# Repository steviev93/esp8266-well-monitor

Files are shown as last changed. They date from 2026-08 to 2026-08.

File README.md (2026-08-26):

ESP8266 Well Water Monitor

A solar-powered IoT system for remotely monitoring residential well-water depth using an ESP8266, ADS1115 ADC, and 4–20 mA submersible pressure sensor.

Overview

The monitor converts the sensor's 4–20 mA output into a measurable voltage using a 150 Ω shunt resistor, producing approximately 0.6–3.0 V across the sensor's operating range. An ADS1115 digitizes the signal and communicates with the ESP8266 over I²C.

The ESP8266 processes the reading, converts it into water-level data, and transmits telemetry over Wi-Fi. The sensor loop is switched by a MOSFET so it can be powered only when a measurement is required.

Hardware
ESP8266 NodeMCU
ADS1115 16-bit ADC
4–20 mA submersible pressure/depth sensor
150 Ω current-shunt resistor
IRLB8721 MOSFET for sensor power control
12 V LiFePO4 battery
Solar charging system
Custom KiCad PCB

KiCad schematic and PCB source files are available in hardware/.

Firmware

Firmware is written in C and organized into separate hardware, driver, service, and application layers.

Key features include:

ADS1115 I²C driver
4–20 mA signal conversion and water-level calculation
Wi-Fi connection management
HTTP telemetry
In-memory buffering during connection failures
NVS-backed storage for retained data/configuration
Automatic replay of buffered telemetry after reconnect
Health monitoring and recovery logic
PCB V1 Erratum

The first PCB revision contained an error in the ADS1115 power connection. The ADC supply was routed to the wrong ESP8266 board power connection rather than the regulated 3.3 V rail, resulting in unstable operation and ESP8266 resets.

The prototype was reworked by cutting the incorrect VCC trace and manually connecting the ADS1115 supply to 3.3 V.

A future PCB revision should correct the power-net assignment in the schematic/layout.

Repository Structure
application/ – sampling, telemetry, buffering, supervision
drivers/ – ADS1115 device driver
hal/ – GPIO and I²C hardware abstraction
services/ – Wi-Fi, HTTP, and persistent storage
hardware/ – KiCad schematic, PCB layout, and schematic image
main/ – application entry point
Status

Functional prototype and firmware complete. Hardware design is retained in the repository for continued PCB revision and field-development work.

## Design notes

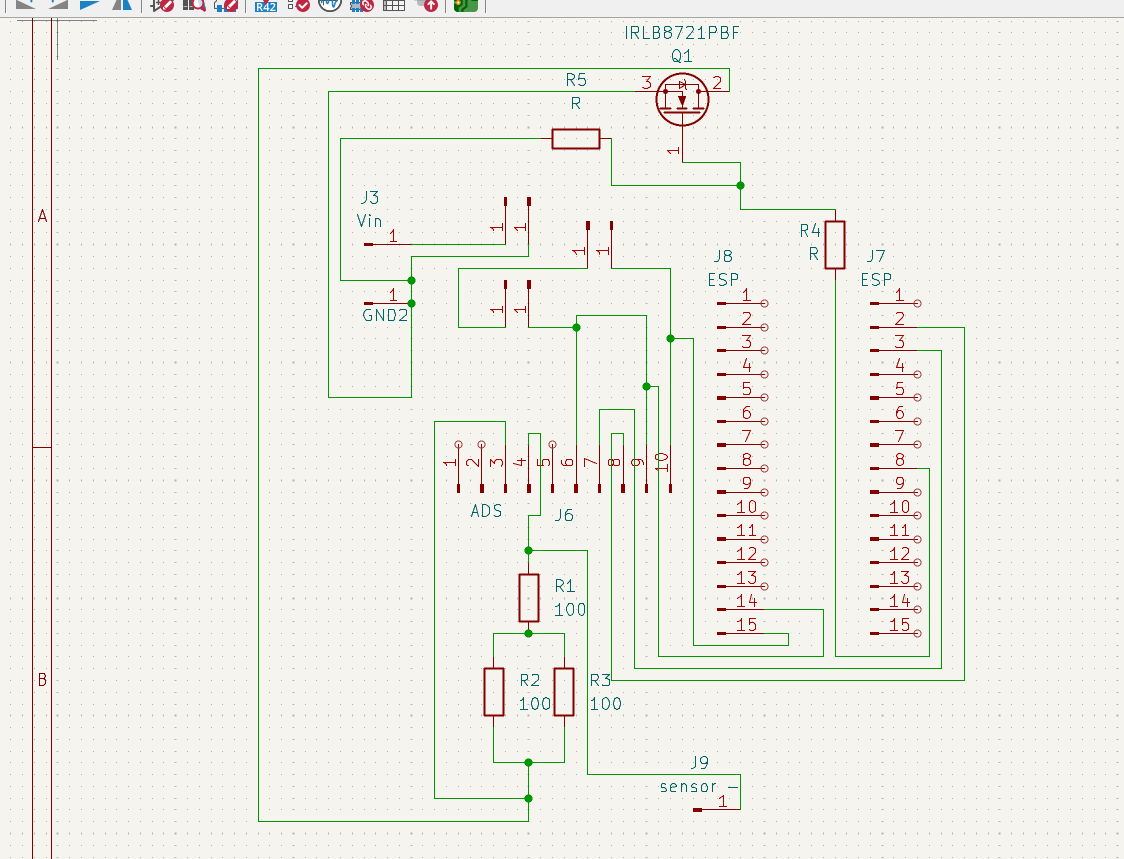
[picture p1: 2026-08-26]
hardware/schematic.png

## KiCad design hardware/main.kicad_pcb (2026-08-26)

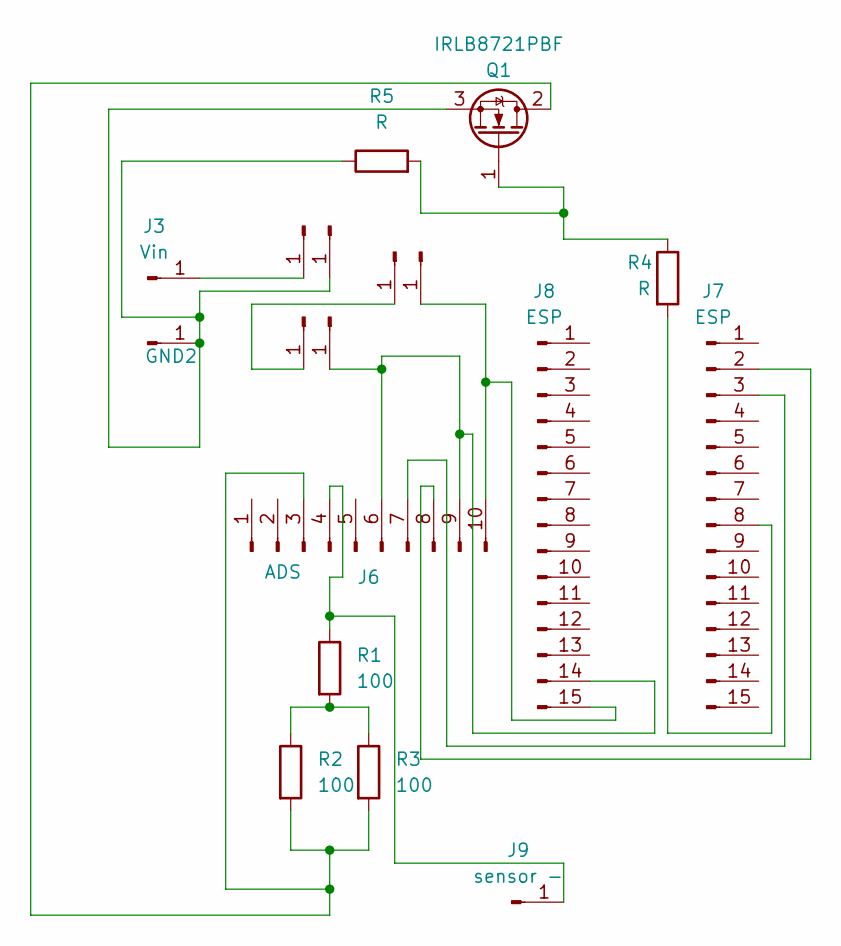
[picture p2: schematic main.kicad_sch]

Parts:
GND2: GND2; PinHeader_1x01_P2.54mm_Vertical
J1: BI+; PinHeader_1x01_P2.54mm_Vertical
J2: BI-; PinHeader_1x01_P2.54mm_Vertical
J3: Vin; PinHeader_1x01_P2.54mm_Vertical
J4: BO+; PinHeader_1x01_P2.54mm_Vertical
J5: BO-; PinHeader_1x01_P2.54mm_Vertical
J6: ADS; PinHeader_1x10_P2.54mm_Vertical
J7, J8: ESP; PinHeader_1x15_P2.54mm_Vertical
J9: sensor -; PinHeader_1x01_P2.54mm_Vertical
J10: F+; PinHeader_1x01_P2.54mm_Vertical
J11: F-; PinHeader_1x01_P2.54mm_Vertical
Q1: IRLB8721PBF; TO-220-3_Vertical
R1, R2, R3: 100; R_Axial_DIN0204_L3.6mm_D1.6mm_P7.62mm_Horizontal
R4, R5: R; R_Axial_DIN0204_L3.6mm_D1.6mm_P7.62mm_Horizontal

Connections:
unnamed: GND2.1, J2.1, Q1.3 (S), R5.1
unnamed: J1.1, J3.1
unnamed: J5.1, J6.6, J6.9, J8.14
unnamed: J6.3, Q1.2 (D), R2.2, R3.2
unnamed: J6.4, J9.1, R1.1
unnamed: J6.7, J7.3
unnamed: J6.8, J7.2
unnamed: J7.8, R4.2
unnamed: J4.1, J10.1
unnamed: J6.10, J8.15, J11.1
unnamed: Q1.1 (G), R4.1, R5.2
unnamed: R1.2, R2.1, R3.1

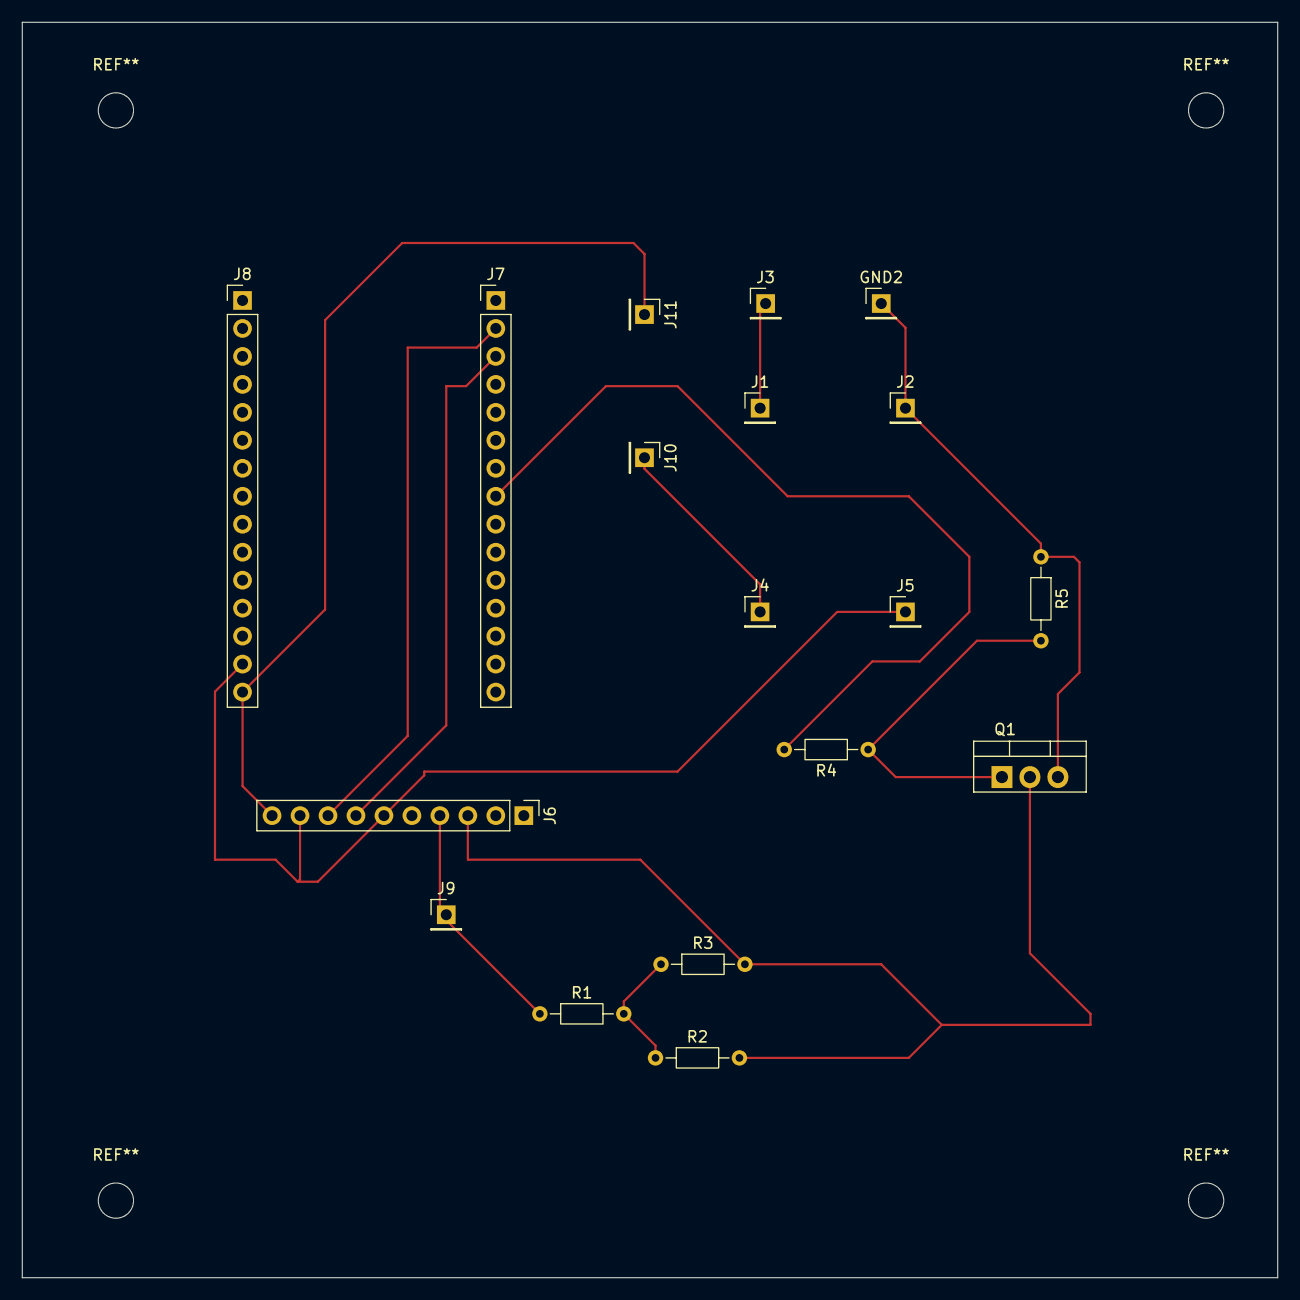
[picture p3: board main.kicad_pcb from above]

Board: 2 copper layers, 114.0 x 114.0 mm, 18 parts (0 on the bottom side), 12 nets.

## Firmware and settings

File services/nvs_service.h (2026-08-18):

#pragma once

#include <stdint.h>
#include <string.h>
#include "../include/app_types.h"

#define DEFAULT_SAMPLE_SETTLE_MS     1000
#define DEFAULT_RETENTION_COUNT      96
#define NVS_READING_CAPACITY         512

esp_err_t nvs_store_pending_reading(const reading_t *reading);

esp_err_t nvs_service_initialize(void);

esp_err_t rebuild_nvs_reading_metadata();

esp_err_t load_nvs_reading(
    reading_t *out
);

esp_err_t pop_metadata();

esp_err_t get_latest_metadata(
    nvs_reading_metadata_t *out);

esp_err_t get_reading_store(
    reading_buffer_t *out);

void save_config(app_config_t *config);

bool load_wifi_credentials(char *ssid, char *password, size_t ssid_size, size_t pass_size);

esp_err_t  save_wifi_credentials(const char *ssid, const char *password);

bool get_latest_config(app_config_t *out);

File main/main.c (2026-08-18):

#include <stdint.h>
#include "freertos/FreeRTOS.h"
#include "../services/wifi_manager.h"
#include "../application/board.h"
#include "../application/telemetry.h"

static const char *TAG = "well_monitor_nodemcu";

void app_main()
{
    BaseType_t task_created;

    ESP_LOGI(TAG, "Booting always-on well monitor");

    gpio_init_all();
    esp_err_t nvs_init = nvs_service_initialize();

    if (nvs_init != ESP_OK) {
        ESP_LOGE(
            TAG,
            "nvs_init failed: %s",
            esp_err_to_name(nvs_init)
        );
        return;
    }

    esp_err_t result = wifi_manager_initialize();
    if (result != ESP_OK) {
        ESP_LOGE(
            TAG,
            "Error initializing Wi-Fi: \n%s",
            esp_err_to_name(result)
        );
    }

    task_created = xTaskCreate(
        telemetry_task, 
        "telemetry_task", 
        TELEMETRY_TASK_STACK_SIZE, 
        NULL, 
        TELEMETRY_TASK_PRIORITY, 
        NULL
    );

    if (task_created != pdPASS) {
        ESP_LOGE(
            TAG,
            "telemetry_task failed to create"
        );
        return;
    }

    ESP_LOGI(TAG, "System ready");
}

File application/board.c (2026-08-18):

#include "board.h"

#define PIN_SENSOR_ENABLE    GPIO_NUM_14  // NodeMCU D5
#define SENSOR_ENABLE_ACTIVE_LEVEL  1
#define SENSOR_ENABLE_IDLE_LEVEL    0
#define CAL_ZERO_UA 4638
#define CAL_NUMERATOR_MM 76
#define CAL_DENOMINATOR_UA 194

#define SENSOR_FULL_SCALE_WATER_MM 6000

#define SHUNT_OHMS_INT 150

static const char *TAG = "board";

static uint32_t millis_now(void)
{
    return xTaskGetTickCount() * portTICK_PERIOD_MS;
}

esp_err_t sensor_enable(bool enabled)
{
    esp_err_t result;
    result = gpio_set_level(
        PIN_SENSOR_ENABLE,
        enabled ? SENSOR_ENABLE_ACTIVE_LEVEL : SENSOR_ENABLE_IDLE_LEVEL
    );
    return result;
}

void reboot_soon()
{
    vTaskDelay(pdMS_TO_TICKS(500));
    esp_restart();
}

void gpio_init_all(void)
{
    gpio_config_t out_conf;
    memset(&out_conf, 0, sizeof(out_conf));

    out_conf.pin_bit_mask =
        (1ULL << PIN_SENSOR_ENABLE);

    out_conf.mode = GPIO_MODE_OUTPUT;
    out_conf.pull_up_en = GPIO_PULLUP_DISABLE;
    out_conf.pull_down_en = GPIO_PULLDOWN_ENABLE;
    out_conf.intr_type = GPIO_INTR_DISABLE;

    gpio_config(&out_conf);

    sensor_enable(false);

    esp_err_t result = i2c_master_bus_init();

    if (result != ESP_OK) {
        ESP_LOGE(
            TAG,
            "I2C initialization failed: %s",
            esp_err_to_name(result)
        );

        return;
    }

    result = ads1115_init();

    if (result != ESP_OK) {
        ESP_LOGE(
            TAG,
            "ADS1115 initialization failed: %s",
            esp_err_to_name(result)
        );
    }
}


bool take_sensor_reading(reading_t *out)
{

    if (out == NULL) {
        return false;
    }
    
    ESP_LOGI(TAG, "Turning sensor loop ON");
    sensor_enable(true);

    app_config_t config;

    if (!get_latest_config(&config)) {
        ESP_LOGE(TAG, "Unable to load application config");
        sensor_enable(false);
        return false;
    }

    vTaskDelay(
        pdMS_TO_TICKS(config.sample_settle_ms)
    );

    float volts_unused = 0.0f;
    int16_t raw = 0;
    bool ok = ads1115_read_differential_a0_a1_raw(&raw, &volts_unused);

    sensor_enable(false);
    ESP_LOGI(TAG, "Turning sensor loop OFF");

    if (!ok) {
        return false;
    }

    /*
       ADS1115 at +/-4.096V:
       1 count = 0.000125 V = 125 microvolts

       shunt_uV = raw * 125
       loop_uA  = shunt_uV / 150 ohms

       Calibration currently uses measured bucket values instead of assuming
       perfect 4.000 mA zero and 20.000 mA full scale.

       Current calibration:
       - 5188 uA ≈ 216 mm
       - 5382 uA ≈ 292 mm

       This gives:
       - slope ≈ 76 mm / 194 uA
       - zero ≈ 4638 uA
    */

    int32_t shunt_uV = (int32_t)raw * 125;
    int32_t shunt_mV = shunt_uV / 1000;
    int32_t loop_uA = shunt_uV / SHUNT_OHMS_INT;

    /*
       Direct calibrated water depth calculation:

       water_level_mm =
           (loop_uA - CAL_ZERO_UA) * (76 mm / 194 uA)

       This avoids first mapping to 4-20mA percent, which was causing
       bad readings because your sensor has a real zero offset.
    */

    int32_t water_level_mm =
        ((loop_uA - CAL_ZERO_UA) * CAL_NUMERATOR_MM) / CAL_DENOMINATOR_UA;

    if (water_level_mm < 0) {
        water_level_mm = 0;
    }

    if (water_level_mm > SENSOR_FULL_SCALE_WATER_MM) {
        water_level_mm = SENSOR_FULL_SCALE_WATER_MM;
    }

    int32_t normalized_permille =
        (water_level_mm * 1000) / SENSOR_FULL_SCALE_WATER_MM;

    if (normalized_permille < 0) {
        normalized_permille = 0;
    }

    if (normalized_permille > 1000) {
        normalized_permille = 1000;
    }

    int32_t level_percent_x100 = normalized_permille * 10;

    memset(out, 0, sizeof(*out));

    out->uptime_ms = millis_now();
    out->ads_raw = raw;
    out->shunt_uV = shunt_uV;
    out->shunt_mV = shunt_mV;
    out->loop_uA = loop_uA;
    out->normalized_permille = normalized_permille;
    out->level_percent_x100 = level_percent_x100;
    out->water_level_mm = water_level_mm;

    ESP_LOGI(
        TAG,
        "Reading: raw=%d, shunt=%ld uV, loop=%ld uA, level=%ld.%02ld%%, water=%ld mm",
        raw,
        (long)shunt_uV,
        (long)loop_uA,
        (long)(level_percent_x100 / 100),
        (long)(level_percent_x100 % 100),
        (long)water_level_mm
    );

    return true;
}

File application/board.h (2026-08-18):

#pragma once

#include <string.h>
#include <stdint.h>

#include "freertos/FreeRTOS.h"
#include "freertos/task.h"
#include "esp_system.h"
#include "esp_err.h"

#include "driver/gpio.h"
#include "../services/nvs_service.h"
#include "../hal/i2c_master.h"
#include "../drivers/ads1115.h"
#include "../include/app_types.h"

#define BOARD_I2C_PORT              I2C_NUM_0
#define BOARD_I2C_SDA_GPIO          GPIO_NUM_4
#define BOARD_I2C_SCL_GPIO          GPIO_NUM_5

#define BOARD_I2C_CLK_STRETCH_TICK  300U
#define BOARD_I2C_TIMEOUT_MS        100U
#define LED_GPIO                    GPIO_NUM_12

#define BOARD_ADS1115_ADDRESS       0x48U
#define BOARD_SAMPLE_INTERVAL_MS    500U

esp_err_t sensor_power_init(void);

void reboot_soon(void);

void gpio_init_all(void);

bool take_sensor_reading(reading_t *out);
